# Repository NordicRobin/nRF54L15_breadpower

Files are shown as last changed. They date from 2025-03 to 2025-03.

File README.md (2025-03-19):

# nRF54L15_breadpower  

<p align="center">
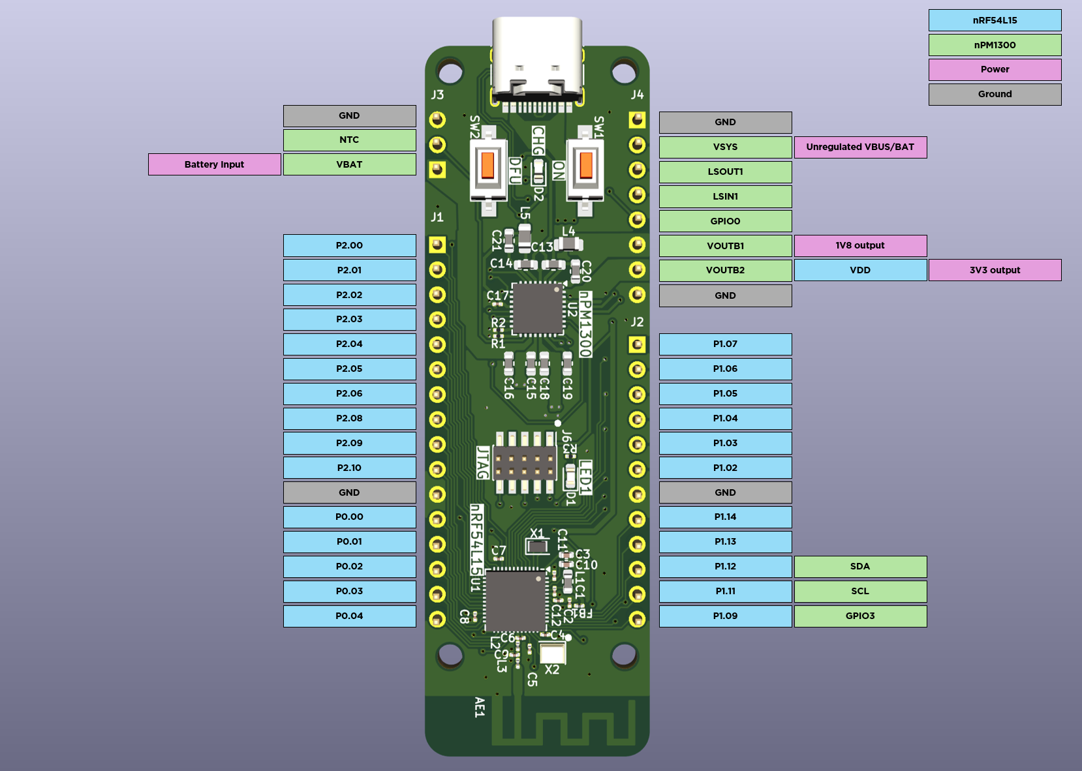
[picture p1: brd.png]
development board designed for breadboard prototyping with support for USB-power and battery charging
  
</p>

The nRF54L15_breadpower is a development board designed for breadboard prototyping with support for directly powering your breadboard project through USB-C, and battery power ing your final project with charging through USB-C.

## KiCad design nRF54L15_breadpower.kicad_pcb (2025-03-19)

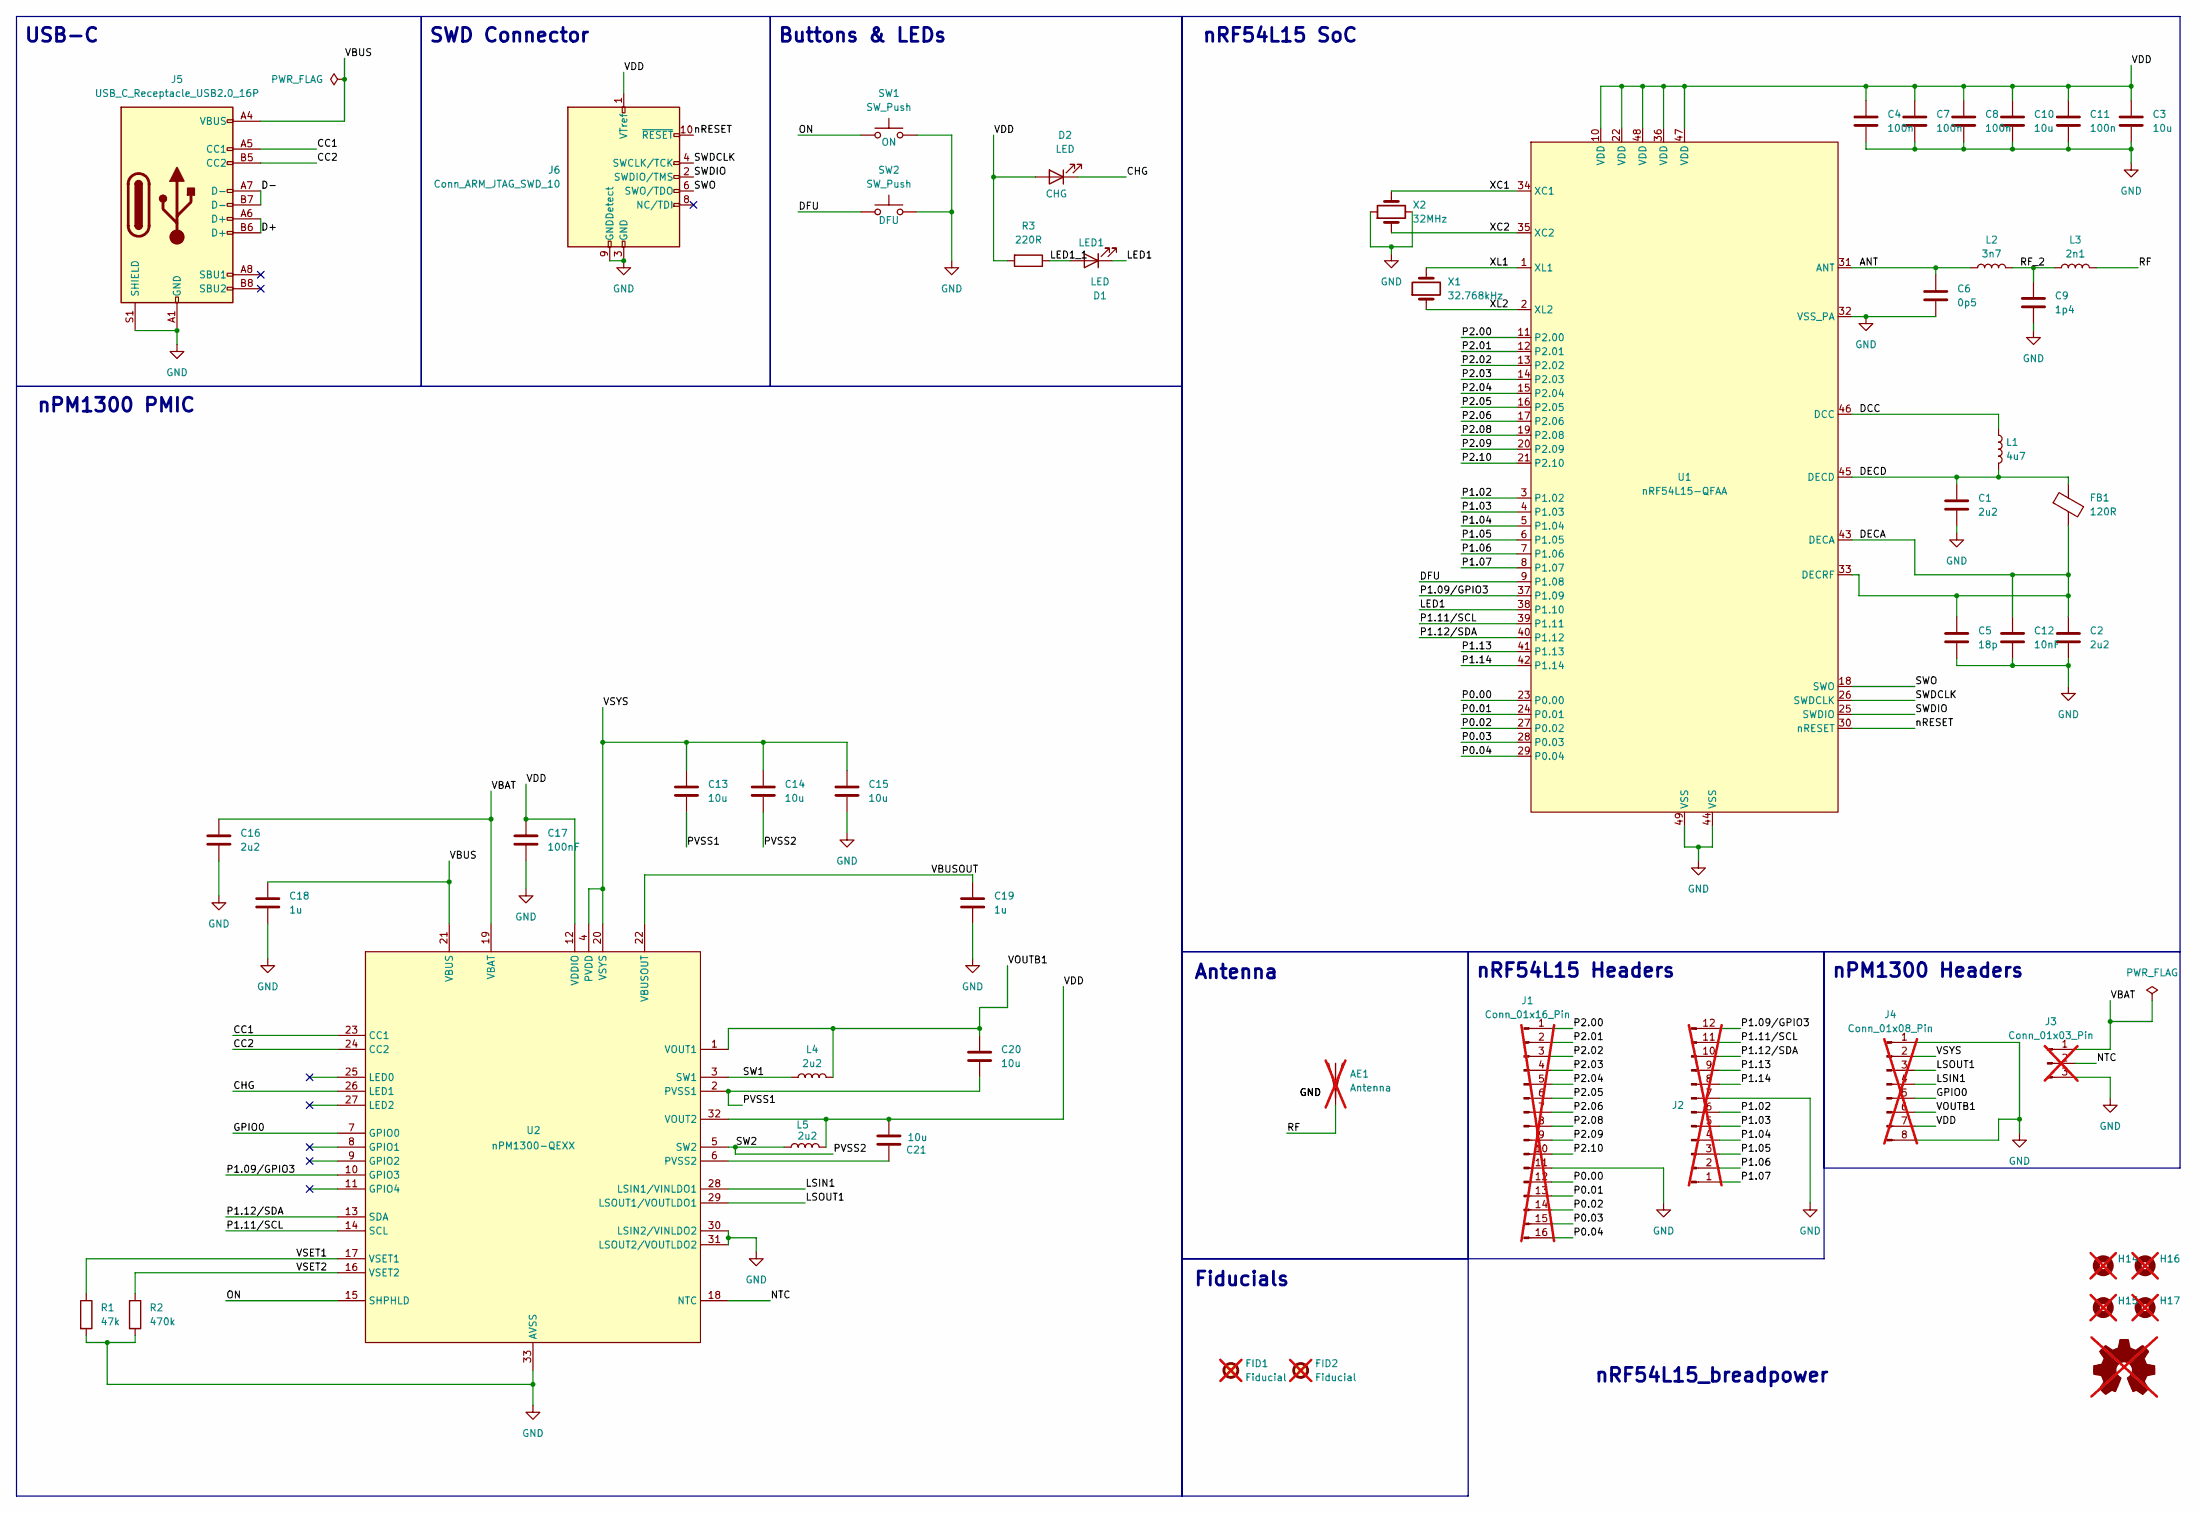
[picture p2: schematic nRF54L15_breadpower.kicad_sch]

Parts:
AE1: Antenna; Texas_SWRA117D_2.4GHz_Left; not fitted
C1, C2: 2u2; C_0201_0603Metric; Manufacturer Part Number GRM033D80E225ME47
C3, C10: 10u; C_0402_1005Metric; Manufacturer Part Number GRM155C80J106ME11D
C4, C7, C8, C11: 100n; C_0201_0603Metric; Manufacturer Part Number GRM033R61C104KE18D
C5: 18p; C_0201_0603Metric; Manufacturer Part Number GCM0335C1E180JA16J
C6: 0p5; C_0201_0603Metric; Manufacturer Part Number GJM0335C1ER50BB01J
C9: 1p4; C_0201_0603Metric; Manufacturer Part Number GJM0335C1E1R4WB01D
C12: 10nF; C_0201_0603Metric; Manufacturer Part Number GRT033R71A103KE01D
C13, C14, C15, C20, C21: 10u; L_0603_1608Metric; Manufacturer Part Number GRM188R61E106MA73D
C16: 2u2; L_0603_1608Metric; Manufacturer Part Number GRM188Z71C225KE43D
C17: 100nF; C_0201_0603Metric; Manufacturer Part Number GRM033R61E104KE14J
C18, C19: 1u; L_0603_1608Metric; Manufacturer Part Number GRM188R61A105KA61J
D1, D2: LED; LED_0603_1608Metric; Manufacturer Part Number IN-S63AT5A
FB1: 120R; L_0201_0603Metric; Manufacturer Part Number BLM03AG121SN1D
FID1, FID2: Fiducial; Fiducial_0.5mm_Mask1.5mm; not fitted
H14, H15, H16, H17: MountingHole; MountingHole_2.5mm; not fitted
J1: Conn_01x16_Pin; PinHeader_1x16_P2.54mm_Vertical; not fitted
J2: Conn_01x12_Pin; PinHeader_1x12_P2.54mm_Vertical; not fitted
J3: Conn_01x03_Pin; PinHeader_1x03_P2.54mm_Vertical; not fitted
J4: Conn_01x08_Pin; PinHeader_1x08_P2.54mm_Vertical; not fitted
J5: USB_C_Receptacle_USB2.0_16P; USB_C_Receptacle_HRO_TYPE-C-31-M-12; Manufacturer Part Number TYPE-C-31-M-12
J6: Conn_ARM_JTAG_SWD_10; PinHeader_2x05_P1.27mm_Vertical_SMD; Manufacturer Part Number FTSH-105-01-L-DV-K-TR
L1: 4u7; L_0603_1608Metric; Manufacturer Part Number MLZ1608M4R7WT000
L2: 3n7; L_0201_0603Metric; Manufacturer Part Number LQP03HQ3N7B02D
L3: 2n1; L_0201_0603Metric; Manufacturer Part Number LQP03HQ2N1W02D
L4, L5: 2u2; L_0805_2012Metric; Manufacturer Part Number MLZ2012M2R2HT000
R1: 47k; R_0201_0603Metric; Manufacturer Part Number RC0201FR-0747KL
R2: 470k; R_0201_0603Metric; Manufacturer Part Number RC0201FR-07470KL
R3: 220R; R_0201_0603Metric; Manufacturer Part Number AC0201FR-13220RL
SW1, SW2: SW_Push; SW_SPST_CK_RS282G05A3; Manufacturer Part Number RS-282G05A3-SM RT
SYM1: Logo_Open_Hardware_Small; not fitted
U1: nRF54L15-QFAA; QFN-48-1EP_6x6mm_P0.4mm_EP4.6x4.6mm; Manufacturer Part Number nRF54L15-QFAA
U2: nPM1300-QEXX; QFN-32-1EP_5x5mm_P0.5mm_EP3.6x3.6mm_ThermalVias; Manufacturer Part Number nPM1300-QEAA
X1: 32.768kHz; Crystal_SMD_2012-2Pin_2.0x1.2mm; Manufacturer Part Number 9HT11-32.768KDZC-T
X2: 32MHz; Crystal_SMD_2016-4Pin_2.0x1.6mm; Manufacturer Part Number MP06003

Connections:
/ANT: C6.1, L2.1, U1.31 (ANT)
/CC1: J5.A5 (CC1), U2.23 (CC1)
/CC2: J5.B5 (CC2), U2.24 (CC2)
/CHG: D2.1 (K), U2.26 (LED1)
/D+: J5.A6 (D+), J5.B6 (D+)
/D-: J5.A7 (D-), J5.B7 (D-)
/DCC: L1.1, U1.46 (DCC)
/DECA: C2.1, C5.1, C12.1, FB1.2, U1.33 (DECRF), U1.43 (DECA)
/DECD: C1.1, FB1.1, L1.2, U1.45 (DECD)
/DFU: SW2.1, U1.9 (P1.08)
/GPIO0: J4.5, U2.7 (GPIO0)
/LED1: D1.1 (K), U1.38 (P1.10)
/LED1_1: D1.2 (A), R3.1
/LSIN1: J4.4, U2.28 (LSIN1/VINLDO1)
/LSOUT1: J4.3, U2.29 (LSOUT1/VOUTLDO1)
/NTC: J3.2, U2.18 (NTC)
/ON: SW1.1, U2.15 (SHPHLD)
/P0.00: J1.12, U1.23 (P0.00)
/P0.01: J1.13, U1.24 (P0.01)
/P0.02: J1.14, U1.27 (P0.02)
/P0.03: J1.15, U1.28 (P0.03)
/P0.04: J1.16, U1.29 (P0.04)
/P1.02: J2.6, U1.3 (P1.02)
/P1.03: J2.5, U1.4 (P1.03)
/P1.04: J2.4, U1.5 (P1.04)
/P1.05: J2.3, U1.6 (P1.05)
/P1.06: J2.2, U1.7 (P1.06)
/P1.07: J2.1, U1.8 (P1.07)
/P1.09/GPIO3: J2.12, U1.37 (P1.09), U2.10 (GPIO3)
/P1.11/SCL: J2.11, U1.39 (P1.11), U2.14 (SCL)
/P1.12/SDA: J2.10, U1.40 (P1.12), U2.13 (SDA)
/P1.13: J2.9, U1.41 (P1.13)
/P1.14: J2.8, U1.42 (P1.14)
/P2.00: J1.1, U1.11 (P2.00)
/P2.01: J1.2, U1.12 (P2.01)
/P2.02: J1.3, U1.13 (P2.02)
/P2.03: J1.4, U1.14 (P2.03)
/P2.04: J1.5, U1.15 (P2.04)
/P2.05: J1.6, U1.16 (P2.05)
/P2.06: J1.7, U1.17 (P2.06)
/P2.08: J1.8, U1.19 (P2.08)
/P2.09: J1.9, U1.20 (P2.09)
/P2.10: J1.10, U1.21 (P2.10)
/PVSS1: C13.2, C20.2, U2.2 (PVSS1)
/PVSS2: C14.2, L5.1, U2.5 (SW2)
/RF: AE1.1 (A), L3.2
/RF_2: C9.1, L2.2, L3.1
/SW1: L4.1, U2.3 (SW1)
/SWDCLK: J6.4 (SWCLK/TCK), U1.26 (SWDCLK)
/SWDIO: J6.2 (SWDIO/TMS), U1.25 (SWDIO)
/SWO: J6.6 (SWO/TDO), U1.18 (SWO)
/VBAT: C16.1, J3.1, U2.19 (VBAT)
/VBUS: C18.1, J5.A4 (VBUS), J5.A9 (VBUS), J5.B4 (VBUS), J5.B9 (VBUS), U2.21 (VBUS)
/VBUSOUT: C19.1, U2.22 (VBUSOUT)
/VDD: C3.1, C4.1, C7.1, C8.1, C10.1, C11.1, C17.1, C21.1, D2.2 (A), J4.7, J6.1 (VTref), L5.2, R3.2, U1.10 (VDD), U1.22 (VDD), U1.36 (VDD), U1.47 (VDD), U1.48 (VDD), U2.12 (VDDIO), U2.32 (VOUT2)
/VOUTB1: C20.1, J4.6, L4.2, U2.1 (VOUT1)
/VSET1: R1.1, U2.17 (VSET1)
/VSET2: R2.1, U2.16 (VSET2)
/VSYS: C13.1, C14.1, C15.1, J4.2, U2.4 (PVDD), U2.20 (VSYS)
/XC1: U1.34 (XC1), X2.3
/XC2: U1.35 (XC2), X2.1
/XL1: U1.1 (XL1), X1.2
/XL2: U1.2 (XL2), X1.1
/nRESET: J6.10 (~RESET), U1.30 (nRESET)
GND: AE1.2 (GND), C1.2, C2.2, C3.2, C4.2, C5.2, C6.2, C7.2, C8.2, C9.2, C10.2, C11.2, C12.2, C15.2, C16.2, C17.2, C18.2, C19.2, J1.11, J2.7, J3.3, J4.1, J4.8, J5.A1 (GND), J5.A12 (GND), J5.B1 (GND), J5.B12 (GND), J5.S1 (SHIELD), J6.3 (GND), J6.5 (GND), J6.9 (GNDDetect), R1.2, R2.2, SW1.2, SW2.2, U1.32 (VSS_PA), U1.44 (VSS), U1.49 (VSS), U2.30 (LSIN2/VINLDO2), U2.31 (LSOUT2/VOUTLDO2), U2.33 (AVSS), X2.2, X2.4
unnamed: C21.2, U2.6 (PVSS2)

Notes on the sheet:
nPM1300 Headers
SWD Connector
nPM1300 PMIC
nRF54L15 Headers
Antenna
Buttons & LEDs
Fiducials
USB-C
nRF54L15_breadpower
nRF54L15 SoC

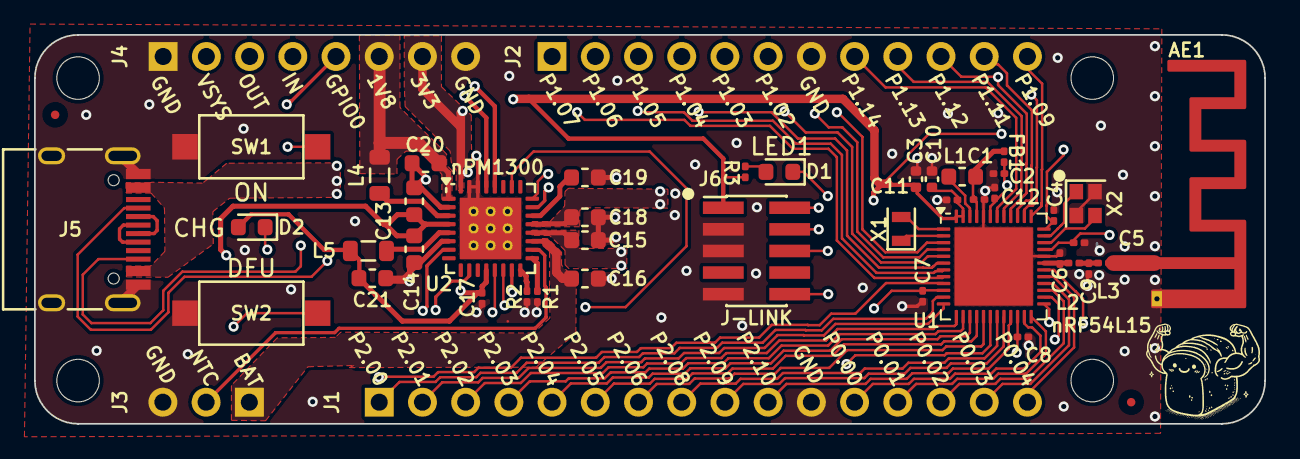
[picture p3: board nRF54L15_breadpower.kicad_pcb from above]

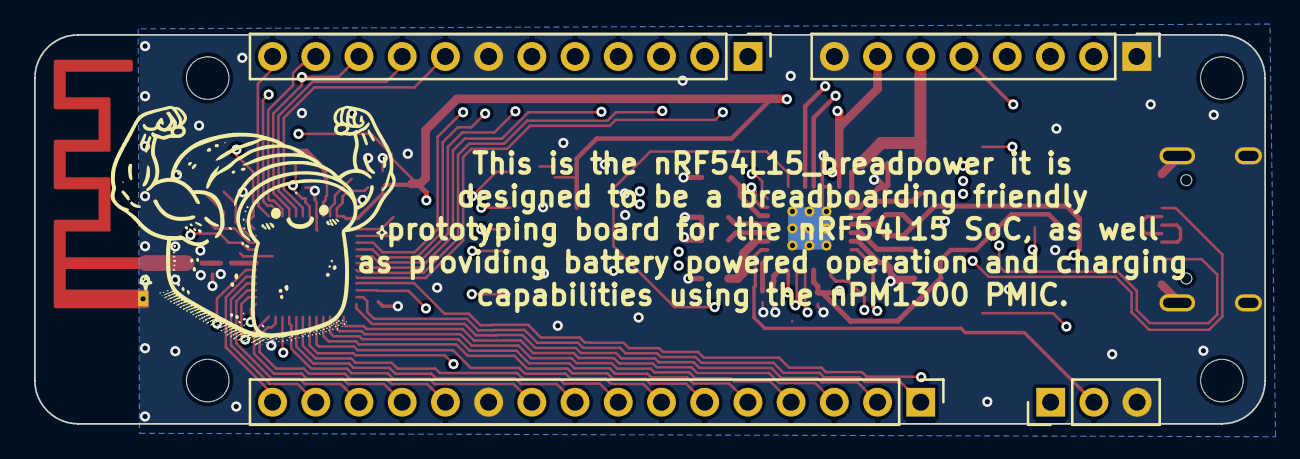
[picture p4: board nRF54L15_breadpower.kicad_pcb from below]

Board: 4 copper layers, 72.3 x 22.9 mm, 51 parts (4 on the bottom side), 66 nets.
